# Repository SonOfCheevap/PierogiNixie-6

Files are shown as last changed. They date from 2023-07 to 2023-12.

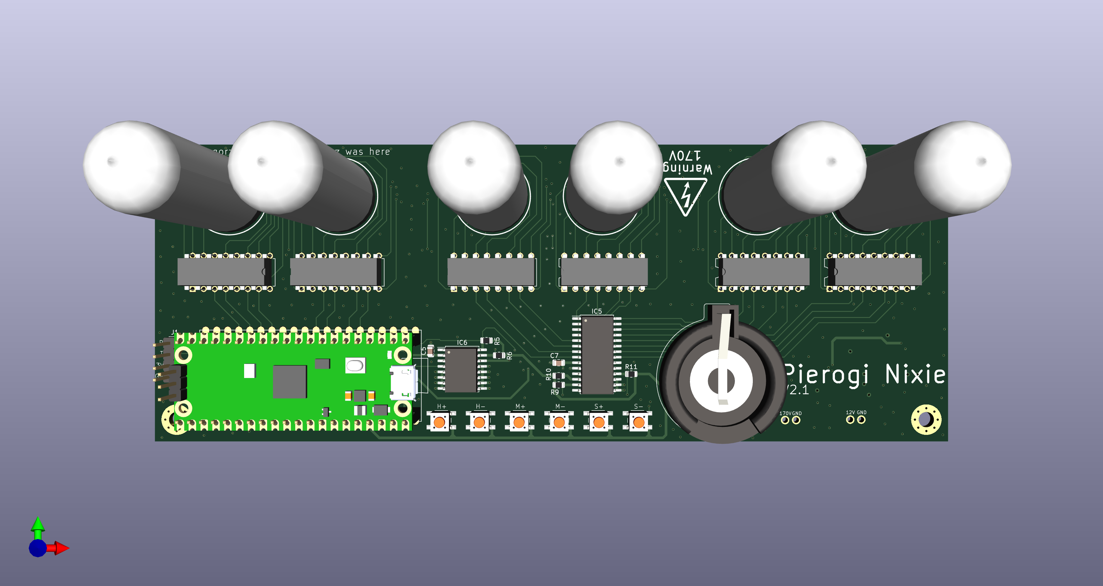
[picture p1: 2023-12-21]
V2.1/Pictures/Top.png

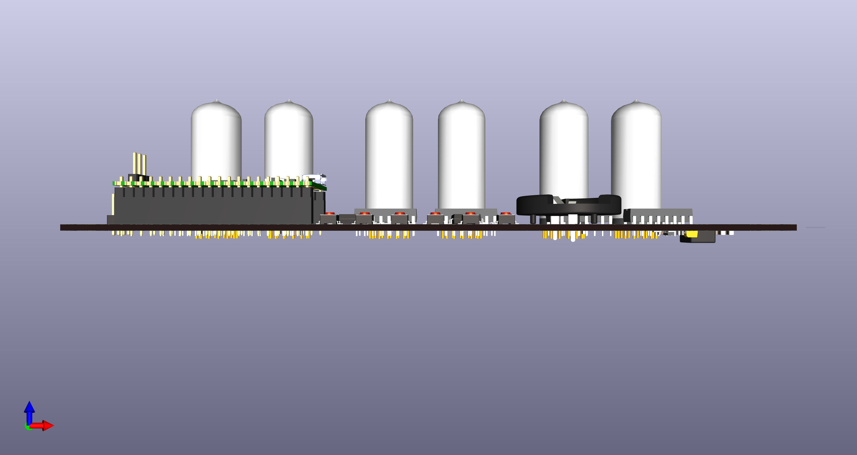
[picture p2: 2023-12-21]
V2.1/Pictures/back.png

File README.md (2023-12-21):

# PierogiNixie-6
A Pi Pico powered nixie tube board that uses 6 IN-14 nixie tubes.

## New with V2.1
- Replaced L7805 Regulator with a TI Buck Converter
- Improved routing of power, with larger traces
- Slightly Wider
- Improved Layout

# Features
- Programmed using a Pi Pico
- ds3231m RTC
- CR2032 Battery for keeping time when off power
- 6x IN-14 Nixie Tubes
- 6x k155id1 Binary to Decimal decoders
- Onboard (and now larger) 12v to 5v Convertor (V2)
- MCP23017-E/SO IO expander
- Buttons that can be programmed to adjust the time
- Breakout header for easier connectivity to a pico probe
- Mounting holes for 4 M3.5x6 screws

# Photos
AS OF 12/20/23

Top
Top

Bottom
Bottom

Front
front

Back
back

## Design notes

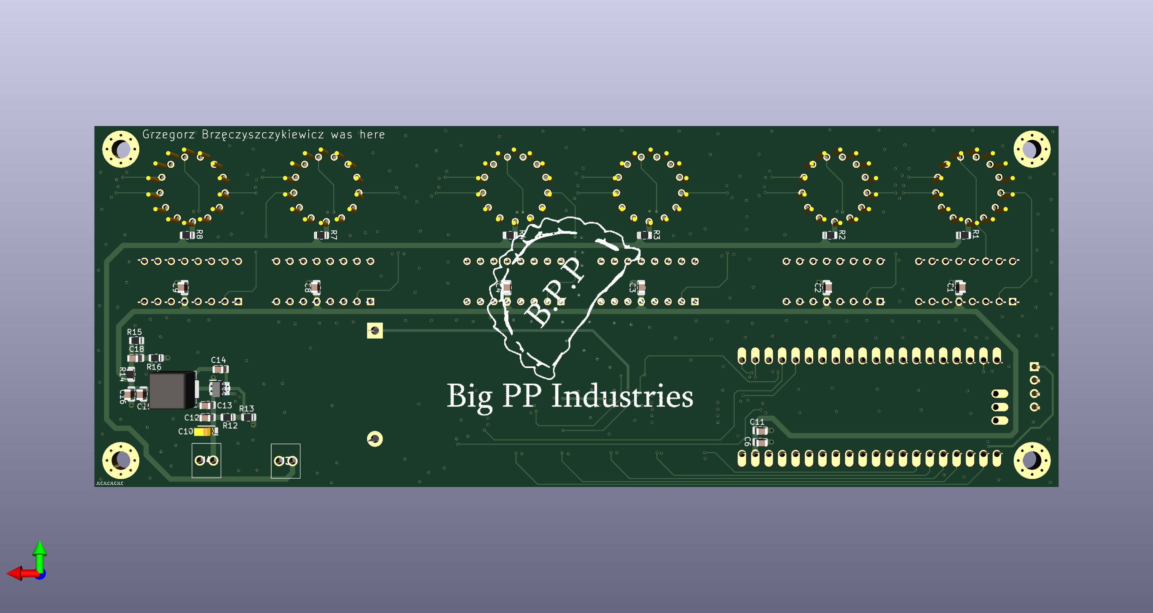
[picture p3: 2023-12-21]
V2.1/Pictures/Bottom.png

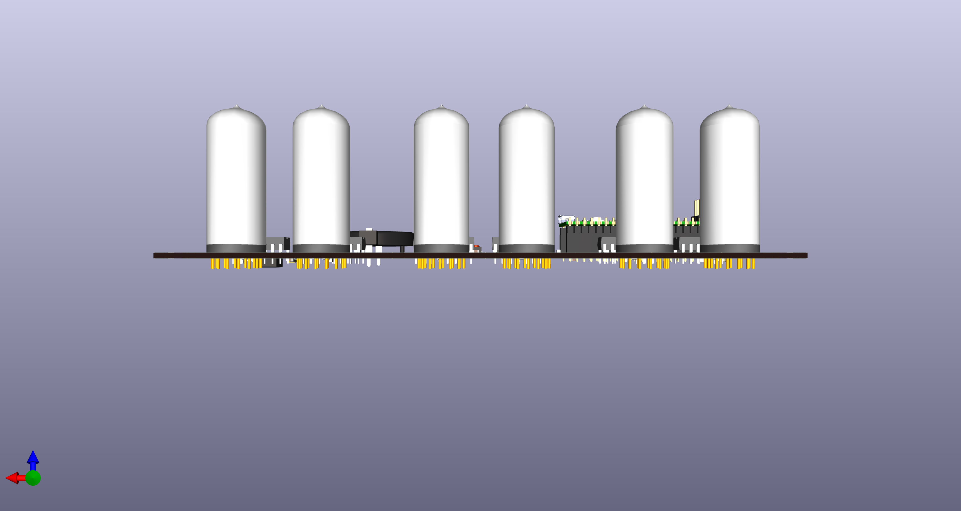
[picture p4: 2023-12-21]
V2.1/Pictures/front.png

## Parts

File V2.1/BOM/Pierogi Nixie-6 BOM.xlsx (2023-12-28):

Part ID | Part Description | Item Link | Cost Per | # Needed | Total
P1 | PI Pico | https://www.digikey.com/en/products/detail/raspberry-pi/SC0915/13624793 | $4.00 | 1 | $4.00
J1 | M20-9990446 | https://www.digikey.com/en/products/detail/harwin-inc/M20-9990446/3728230?s=N4IgTCBcDaILJgAwFoCc7EBZMDYQF0BfIA | $0.21 | 1 | $0.21
J3, J4 | OSTVN02A150 | https://www.digikey.com/en/products/detail/on-shore-technology-inc/OSTVN02A150/1588862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 | $0.92 | 2 | $1.84
IC1, IC2, IC3, IC4, IC7, IC8 | K155ID1 | https://www.ebay.com/itm/183563404353 | $2.98 | 6 | $17.88
IC5 | MCP23017-E_SO | https://www.digikey.com/en/products/detail/microchip-technology/mcp23017-e-so/894271 | $1.62 | 1 | $1.62
IC6 | DS3231M+TRL | https://www.digikey.com/en/products/detail/analog-devices-inc-maxim-integrated/DS3231M-TRL/2402421 | $9.81 | 1 | $9.81
IC9 | TPS54302DDCT | https://www.digikey.com/en/products/detail/texas-instruments/TPS54302DDCT/6123254 | $2.01 | 1 | $2.01
N1, N2, N3, N4, N5, N6 | IN-14 Nixie Tubes | N/A | $10.00 | 6 | $60.00
BAT1 | CR2032 Battery Holder | https://www.digikey.com/en/products/detail/keystone-electronics/106/27386 | $1.34 | 1 | $1.34
S1, S2, S3, S4, S5, S6 | PTS647SN50SMTR2LFS | https://www.digikey.com/en/products/detail/c-k/pts-647-sn50-smtr2-lfs/9649857 | $0.20 | 6 | $1.20
C1, C2, C3, C4, C5, C6, C7, C8, C9, C11, C13, C14 | 0805 100nf/.1uF Capacitor | https://www.digikey.com/en/products/detail/samsung-electro-mechanics/CL21B104KBCNNNC/3886661 | $0.10 | 11 | $1.10
C10 | 47uF | https://www.digikey.com/en/products/detail/kyocera-avx/F931A476KAA/4005057 | $0.72 | 10 | $7.20
C11, C12 | 10uF | https://www.digikey.com/en/products/detail/samsung-electro-mechanics/CL21A106KOQNNNE/3886754 | $0.10 | 2 | $0.20
C15, C16 | 22uF | https://www.digikey.com/en/products/detail/samsung-electro-mechanics/CL21A226KOQNNNE/5961010 | $0.33 | 2 | $0.66
C17 | 75pF | https://www.digikey.com/en/products/detail/yageo/CC0805JRNPO9BN750/5884054 | $0.14 | 1 | $0.14
R1, R2, R3, R4, R5, R6, R7, R8, R9, R10, R11 | 0805 10K Resistor | https://www.digikey.com/en/products/detail/vishay-dale/RCS080510K0FKEA/5866991 | $0.10 | 11 | $1.10
R12 | 511K | https://www.digikey.com/en/products/detail/koa-speer-electronics-inc/RK73H2ARTTD5113F/12548650 | $0.19 | 1 | $0.19
R13 | 105K | https://www.digikey.com/en/products/detail/koa-speer-electronics-inc/RK73H2ATTD1053F/10234720 | $0.10 | 1 | $0.10
R14 | 49.9 ohm | https://www.digikey.com/en/products/detail/vishay-dale/CRCW080549R9FKEAHP/2222324 | $0.20 | 1 | $0.20
R15 | 100K | https://www.digikey.com/en/products/detail/koa-speer-electronics-inc/SG73P2ATTD1003F/10188411 | $0.18 | 1 | $0.18
R16 | 13.3K | https://www.digikey.com/en/products/detail/vishay-dale/CRCW080513K3FKEAHP/2227086 | $0.20 | 1 | $0.20
L1 | 10uH | https://www.digikey.com/en/products/detail/abracon-llc/ASPI-0630LR-100M-T15/3059602 | $0.72 | 1 | $0.72
Misc | K155ID1 Chip Sockets | https://www.digikey.com/en/products/detail/on-shore-technology-inc/ED16DT/4147596 | $0.26 | 6 | $1.56
Misc | 20 pin male header | https://www.digikey.com/en/products/detail/adam-tech/PH1-20-UA/9830398 | $0.32 | 6 | $1.92
Misc | 20 pin female header | https://www.digikey.com/en/products/detail/sullins-connector-solutions/PPTC201LFBN-RC/810158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 | $1.23 | 1 | $1.23
Misc | 3 pin male header | https://www.digikey.com/en/products/detail/sullins-connector-solutions/PPPC031LFBN-RC/810175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 | $0.37 | 1 | $0.37
Misc | 3 female header | https://www.digikey.com/en/products/detail/sullins-connector-solutions/PREC003SAAN-RC/2774851 | $0.09 | 1 | $0.09
Board | PierogiNixie-6 | N/A | $7.00 | 1 | $7.00
 |  |  |  | Final Total: | $124.07

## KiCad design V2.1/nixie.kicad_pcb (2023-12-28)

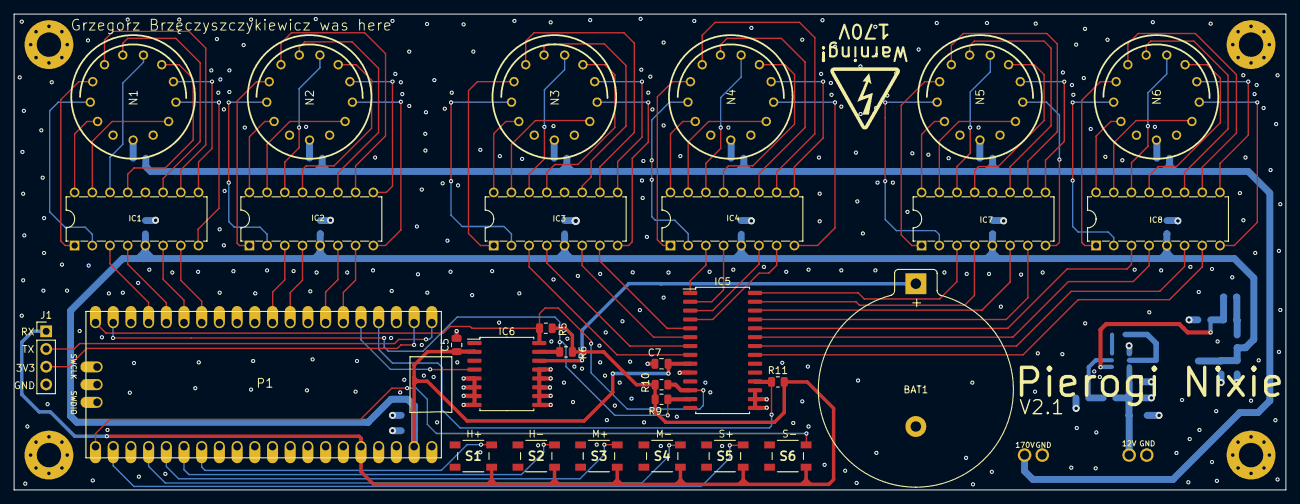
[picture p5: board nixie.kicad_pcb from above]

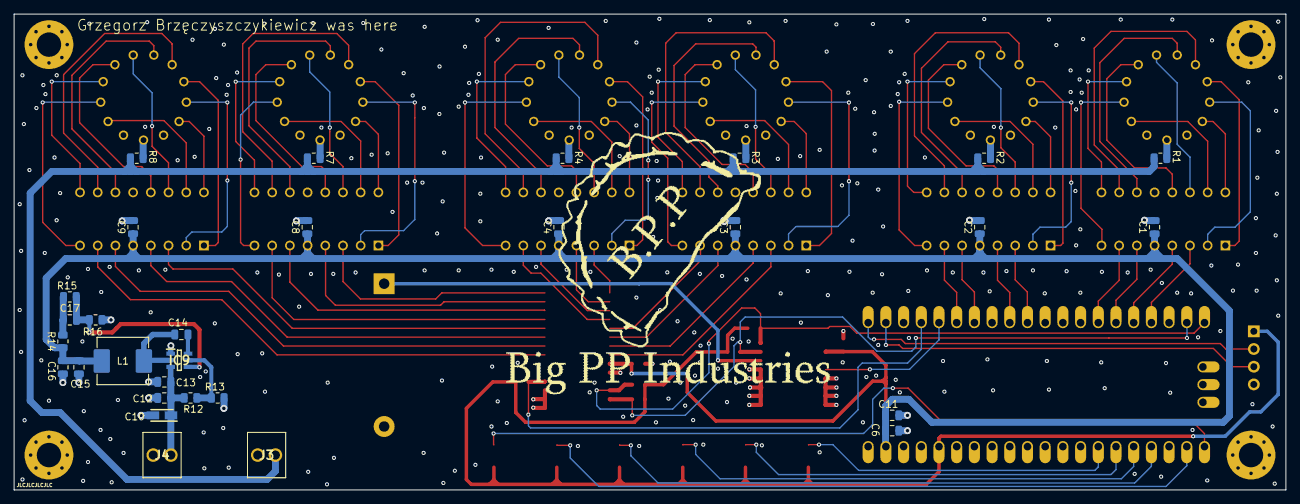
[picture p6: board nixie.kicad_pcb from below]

Board: 4 copper layers, 182.5 x 68.3 mm, 66 parts (37 on the bottom side), 113 nets.

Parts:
BAT1: 36-106-ND; BatteryHolder_Keystone_106_1x20mm
C1, C2, C3, C4, C5, C6, C7, C8, C9: 100nf; C_0805_2012Metric
C10: 47uF; CAPPM3216X180N
C11, C12: 10uF; C_0805_2012Metric
C13, C14: .1uF; C_0805_2012Metric
C15, C16: 22uF; C_0805_2012Metric
C17: 75pF; C_0805_2012Metric
H1, H2, H3, H4: MountingHole; MountingHole_3.5mm_Pad_Via
IC1, IC2, IC3, IC4, IC7, IC8: K155ID1; DIP16-2.54-19.2X7.62MM
IC5: MCP23017-E_SO; SOIC-28W_7.5x17.9mm_P1.27mm
IC6: DS3231M+TRL; SOIC-16W_7.5x10.3mm_P1.27mm
IC9: TPS54302DDCT; SOT95P280X110-6N
J1: M20-9990446; PinHeader_1x04_P2.54mm_Vertical
J3, J4: OSTVN02A150
L1: 10uH; L_Abracon_ASPI-0630LR
N1, N2, N3, N4, N5, N6: IN-14
P1: RPI_PICO-TH; RPI_PICO_TH
R1, R2, R3, R4, R5, R6, R7, R8, R9, R10, R11: 10k; R_0805_2012Metric
R12: 511K; R_0805_2012Metric
R13: 105K; R_0805_2012Metric
R14: 49.9; R_0805_2012Metric
R15: 100K; R_0805_2012Metric
R16: 13.3K; R_0805_2012Metric
S1, S2, S3, S4, S5, S6: PTS647SN50SMTR2LFS
U$2: HVSMALL
U$3: BIGPP

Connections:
+3V3: J1.1, P1.3V3, R5.1, R6.2, R9.1, R10.1, R11.2, S1.4, S2.4, S3.4, S4.4, S5.4, S6.4
+5V: C1.1, C2.1, C3.1, C4.1, C5.1, C6.1, C7.1, C8.1, C9.1, C11.1, C15.1, C16.1, IC1.5 (VCC), IC2.5 (VCC), IC3.5 (VCC), IC4.5 (VCC), IC5.9 (VDD), IC6.2 (VCC), IC7.5 (VCC), IC8.5 (VCC), L1.2, P1.VSYS, R14.1
+12V: C10.1, C12.1, C13.1, IC9.3 (VIN), J4.1, R12.1
/170V1: N1.A, R1.2
/170V2: N2.A, R2.2
/170V3: N3.A, R3.2
/170V4: N4.A, R4.2
/170V5: N5.A, R7.1
/170V6: N6.A, R8.1
/A1: IC1.3 (A), P1.GP13
/A2: IC2.3 (A), P1.GP7
/A3: IC3.3 (A), IC5.8 (GPB7)
/A4: IC4.3 (A), IC5.1 (GPB0)
/A5: IC5.28 (GPA7), IC7.3 (A)
/A6: IC5.24 (GPA3), IC8.3 (A)
/B1: IC1.6 (B), P1.GP11
/B2: IC2.6 (B), P1.GP5
/B3: IC3.6 (B), IC5.6 (GPB5)
/B4: IC4.6 (B), IC5.3 (GPB2)
/B5: IC5.26 (GPA5), IC7.6 (B)
/B6: IC5.22 (GPA1), IC8.6 (B)
/C1: IC1.7 (C), P1.GP10
/C2: IC2.7 (C), P1.GP4
/C3: IC3.7 (C), IC5.5 (GPB4)
/C4: IC4.7 (C), IC5.4 (GPB3)
/C5: IC5.25 (GPA4), IC7.7 (C)
/C6: IC5.21 (GPA0), IC8.7 (C)
/D1: IC1.4 (D), P1.GP12
/D2: IC2.4 (D), P1.GP6
/D3: IC3.4 (D), IC5.7 (GPB6)
/D4: IC4.4 (D), IC5.2 (GPB1)
/D5: IC5.27 (GPA6), IC7.4 (D)
/D6: IC5.23 (GPA2), IC8.4 (D)
/N10: IC1.16 (0), N1.0
/N11: IC1.15 (1), N1.1
/N12: IC1.8 (2), N1.2
/N13: IC1.9 (3), N1.3
/N14: IC1.13 (4), N1.4
/N15: IC1.14 (5), N1.5
/N16: IC1.11 (6), N1.6
/N17: IC1.10 (7), N1.7
/N18: IC1.1 (8), N1.8
/N19: IC1.2 (9), N1.9
/N20: IC2.16 (0), N2.0
/N21: IC2.15 (1), N2.1
/N22: IC2.8 (2), N2.2
/N23: IC2.9 (3), N2.3
/N24: IC2.13 (4), N2.4
/N25: IC2.14 (5), N2.5
/N26: IC2.11 (6), N2.6
/N27: IC2.10 (7), N2.7
/N28: IC2.1 (8), N2.8
/N29: IC2.2 (9), N2.9
/N30: IC3.16 (0), N3.0
/N31: IC3.15 (1), N3.1
/N32: IC3.8 (2), N3.2
/N33: IC3.9 (3), N3.3
/N34: IC3.13 (4), N3.4
/N35: IC3.14 (5), N3.5
/N36: IC3.11 (6), N3.6
/N37: IC3.10 (7), N3.7
/N38: IC3.1 (8), N3.8
/N39: IC3.2 (9), N3.9
/N40: IC4.16 (0), N4.0
/N41: IC4.15 (1), N4.1
/N42: IC4.8 (2), N4.2
/N43: IC4.9 (3), N4.3
/N44: IC4.13 (4), N4.4
/N45: IC4.14 (5), N4.5
/N46: IC4.11 (6), N4.6
/N47: IC4.10 (7), N4.7
/N48: IC4.1 (8), N4.8
/N49: IC4.2 (9), N4.9
/N50: IC7.16 (0), N5.0
/N51: IC7.15 (1), N5.1
/N52: IC7.8 (2), N5.2
/N53: IC7.9 (3), N5.3
/N54: IC7.13 (4), N5.4
/N55: IC7.14 (5), N5.5
/N56: IC7.11 (6), N5.6
/N57: IC7.10 (7), N5.7
/N58: IC7.1 (8), N5.8
/N59: IC7.2 (9), N5.9
/N60: IC8.16 (0), N6.0
/N61: IC8.15 (1), N6.1
/N62: IC8.8 (2), N6.2
/N63: IC8.9 (3), N6.3
/N64: IC8.13 (4), N6.4
/N65: IC8.14 (5), N6.5
/N66: IC8.11 (6), N6.6
/N67: IC8.10 (7), N6.7
/N68: IC8.1 (8), N6.8
/N69: IC8.2 (9), N6.9
/RSTC: IC6.4 (~RST), P1.GP3
/RSTIO: IC5.18 (~RESET), P1.GP2, R11.1
/RX: J1.2, P1.GP0
/S1: P1.GP21, S1.1
/S2: P1.GP20, S2.1
/S3: P1.GP19, S3.1
/S4: P1.GP18, S4.1
/S5: P1.GP17, S5.1
/S6: P1.GP16, S6.1
/SCL1: IC5.12 (SCK), IC6.16 (SCL), P1.GP15, R5.2, R10.2
/SDA1: IC5.13 (SDA), IC6.15 (SDA), P1.GP14, R6.1, R9.2
/TX: J1.3, P1.GP1
GND: BAT1.2 (-), C1.2, C2.2, C3.2, C4.2, C5.2, C6.2, C7.2, C8.2, C9.2, C10.2, C11.2, C12.2, C13.2, C15.2, C16.2, IC1.12 (GND), IC2.12 (GND), IC3.12 (GND), IC4.12 (GND), IC5.10 (VSS), IC5.15 (A0), IC5.16 (A1), IC5.17 (A2), IC6.5 (GND), IC6.6 (GND), IC6.7 (GND), IC6.8 (GND), IC6.9 (GND), IC6.10 (GND), IC6.11 (GND), IC6.12 (GND), IC6.13 (GND), IC7.12 (GND), IC8.12 (GND), IC9.1 (GND), J1.4, J3.2, J4.2, P1.AGND, P1.GND@1 (GND), P1.GND@2 (GND), P1.GND@3 (GND), P1.GND@4 (GND), P1.GND@5 (GND), P1.GND@6 (GND), P1.GND@7 (GND), P1.GND@8 (GND), R13.2, R16.2
unnamed: BAT1.1 (+), IC6.14 (VBAT)
unnamed: C17.1, R14.2, R15.1
unnamed: C14.1, IC9.6 (BOOT)
unnamed: IC9.5 (EN), R12.2, R13.1
unnamed: C17.2, IC9.4 (FB), R15.2, R16.1
unnamed: C14.2, IC9.2 (SW), L1.1
VCC: J3.1, R1.1, R2.1, R3.1, R4.1, R7.2, R8.2

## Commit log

2023-07-02 WIP files
    [nixie.kicad_pcb, nixie.kicad_sch]
2023-07-02 Changes to schematic
    [nixie.kicad_pcb, nixie.kicad_sch]
2023-07-04 Started routing
    [nixie.kicad_pcb, nixie.kicad_sch]
2023-07-06 made minor changes to routing
    [nixie.kicad_pcb, nixie.kicad_sch]
2023-07-07 added vias, made small routing adjustments
    [Pierogi Nixie-6 BOM.xlsx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]
2023-07-08 added reset line for clock
    [nixie-B_Cu.gbr, nixie-B_Mask.gbr, nixie-B_Paste.gbr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]
2023-12-14 Started v1.1, schematic redone, board WIP'
    [Pierogi Nixie-6 BOM.xlsx, nixie.kicad_pcb, nixie.kicad_sch]
2023-12-14 Reorganizing Repo
    [Pierogi Nixie-6 BOM.xlsx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]
2023-12-15 Adjsuted more items in schematic, began layout
    [nixie.kicad_pcb, nixie.kicad_sch]
2023-12-20 Continued routing
    [nixie.kicad_pcb]
2023-12-21 Finished routing, added vias
    [nixie.kicad_pcb]
2023-12-21 Added a few extra vias
    [nixie.kicad_pcb]
2023-12-21 Updated images, added gerbers
    [nixie-B_Cu.gbl, nixie-B_Mask.gbs, nixie-B_Paste.gbp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]
2023-12-28 Updated bom, slightchanges to footprint indicators
    [Pierogi Nixie-6 BOM.xlsx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]
